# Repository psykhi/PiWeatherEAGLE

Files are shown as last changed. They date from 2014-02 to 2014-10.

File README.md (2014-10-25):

PiWeatherEAGLE
==============

This repository contains EAGLE boards/schematics/gerber files for the PiWeather weather station project.
To learn more, see http://theboredengineers.com.

main_indoor_sensor is an indoor board that can monitor temperature, humidity and pressure.
It is described here : http://theboredengineers.com/2014/05/piweather-part-4-first-pcbs/

rpi_shield is Raspberry Pi shield hosting a nRF24L01+ RF transimtter. 

If you are interested in this project, please visit http://theboredengineers.com, let a comment
or send an email to alex@theboredengineers.com

:)

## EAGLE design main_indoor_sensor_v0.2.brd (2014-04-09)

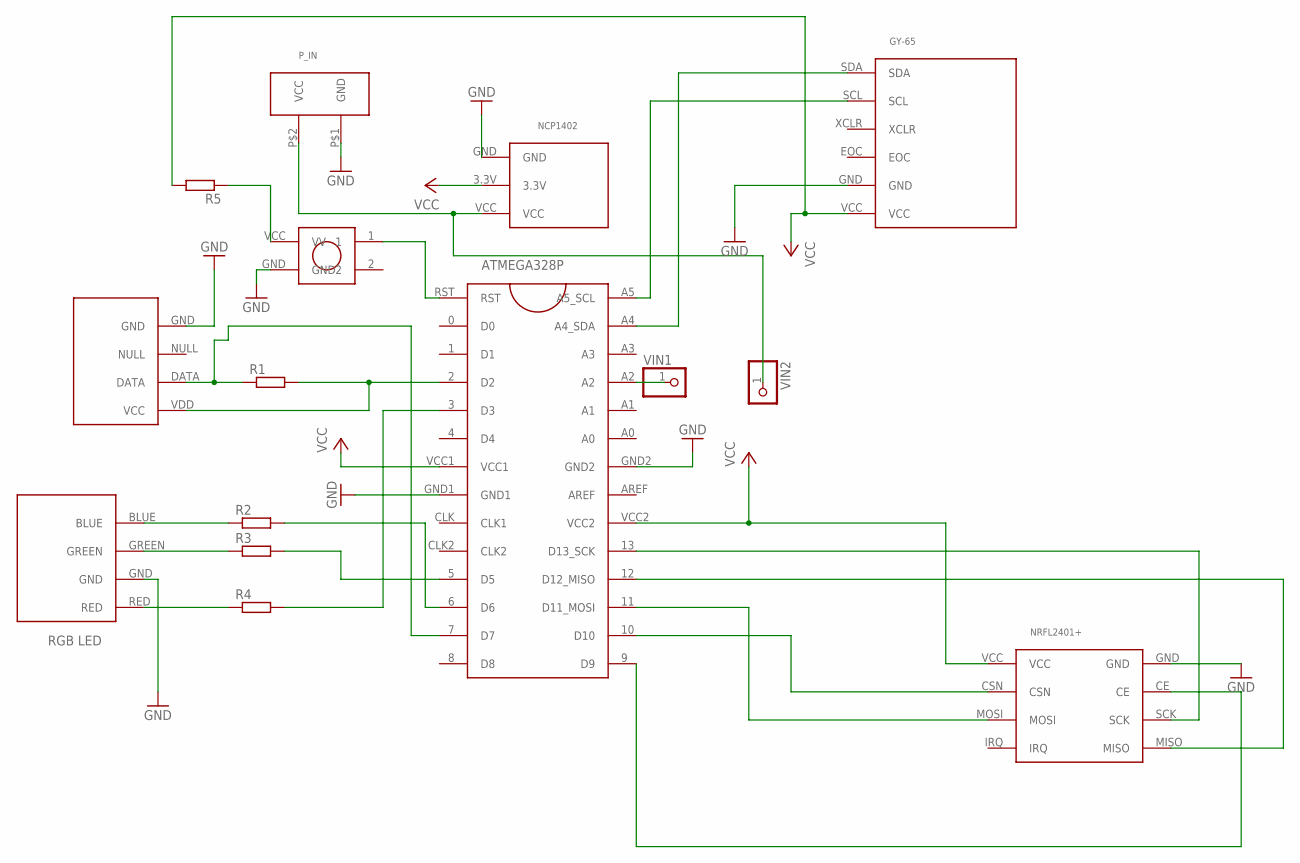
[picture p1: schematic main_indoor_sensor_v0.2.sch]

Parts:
GY-65: GY-65; GY_65
NCP1402: NCP1402SPARKFUN; NCP1402
NRFL2401+: NRFL24L01_8P; NRF24L01_10P
P_IN: 2PINCONNECTORSIMPLE; 2PINCONNECTOR
R1, R2, R3, R4, R5: R0204/7; 0204/7
U$1: ATMEGA328PARDUINO; ATMEGA328P
U$2: KRS_0612_OK; KRS0612_RIGHT
U$3: DHT22WHITE; DHT22
U$6: RGB_LED5MM; RGB_LED
VIN1, VIN2: PINHD-1X1; 1X01

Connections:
GND: GY-65.GND, NCP1402.GND, NRFL2401+.GND, P_IN.P$1 (GND), U$1.GND1, U$1.GND2, U$2.GND, U$3.GND, U$6.GND
unnamed: GY-65.SDA, U$1.A4 (A4_SDA)
unnamed: GY-65.SCL, U$1.A5 (A5_SCL)
unnamed: NRFL2401+.SCK, U$1.13 (D13_SCK)
unnamed: NRFL2401+.MISO, U$1.12 (D12_MISO)
unnamed: NRFL2401+.MOSI, U$1.11 (D11_MOSI)
unnamed: R1.2, U$1.2 (D2), U$3.VDD (VCC)
unnamed: R1.1, U$1.7 (D7), U$3.DATA
unnamed: R4.2, U$1.3 (D3)
unnamed: R2.1, U$6.BLUE
unnamed: R3.1, U$6.GREEN
unnamed: R2.2, U$1.6 (D6)
unnamed: R3.2, U$1.5 (D5)
unnamed: R4.1, U$6.RED
unnamed: NRFL2401+.CSN, U$1.10 (D10)
unnamed: NRFL2401+.CE, U$1.9 (D9)
unnamed: U$1.RST, U$2.1
unnamed: NCP1402.VCC, P_IN.P$2 (VCC), VIN2.1
unnamed: R5.1, U$2.VCC (VV)
unnamed: U$1.A2, VIN1.1
VCC: GY-65.VCC, NCP1402.3.3V, NRFL2401+.VCC, R5.2, U$1.VCC1, U$1.VCC2

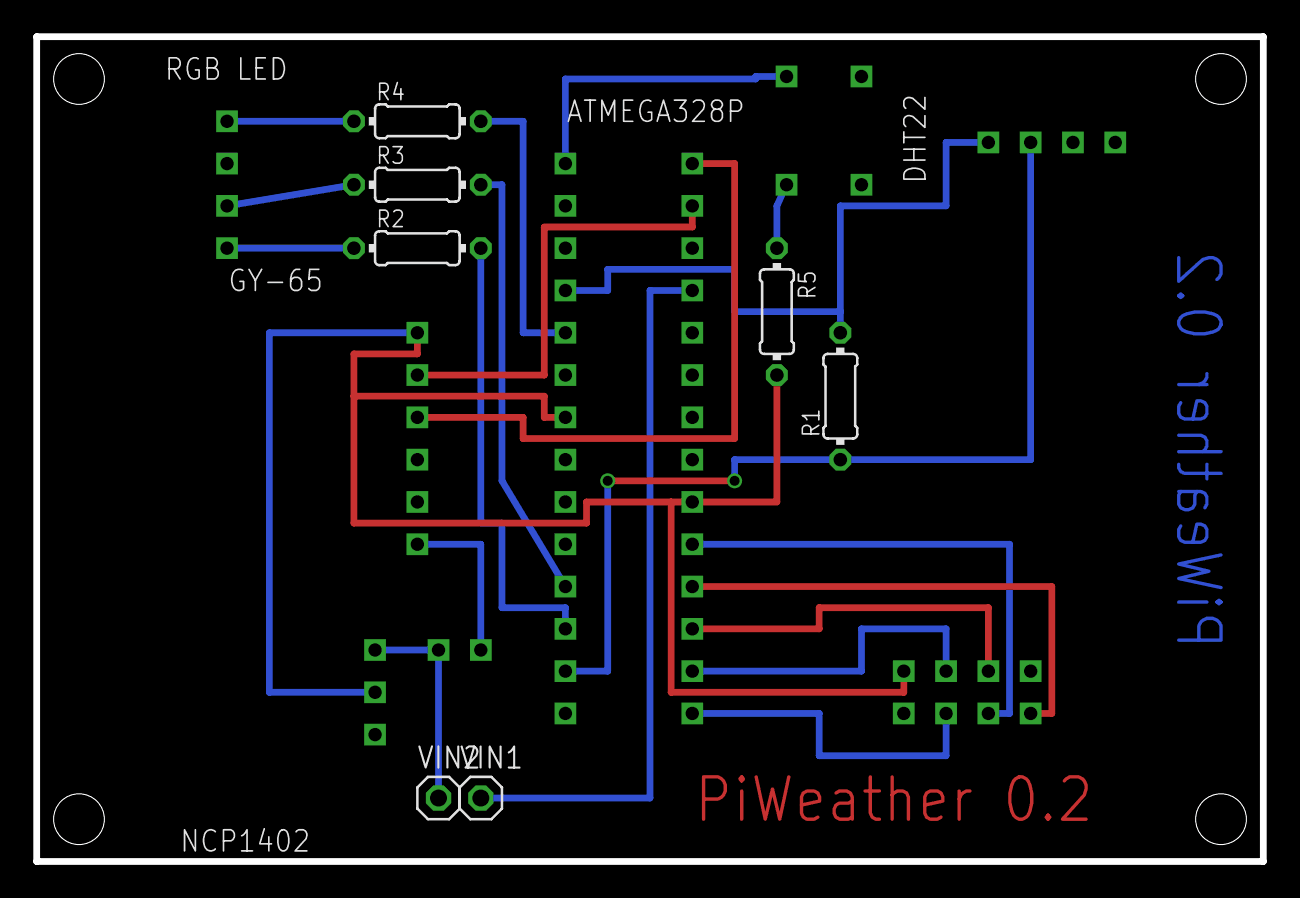
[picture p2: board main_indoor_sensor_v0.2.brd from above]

Board: 2 copper layers, 73.7 x 49.5 mm, 15 parts (0 on the bottom side), 21 nets.

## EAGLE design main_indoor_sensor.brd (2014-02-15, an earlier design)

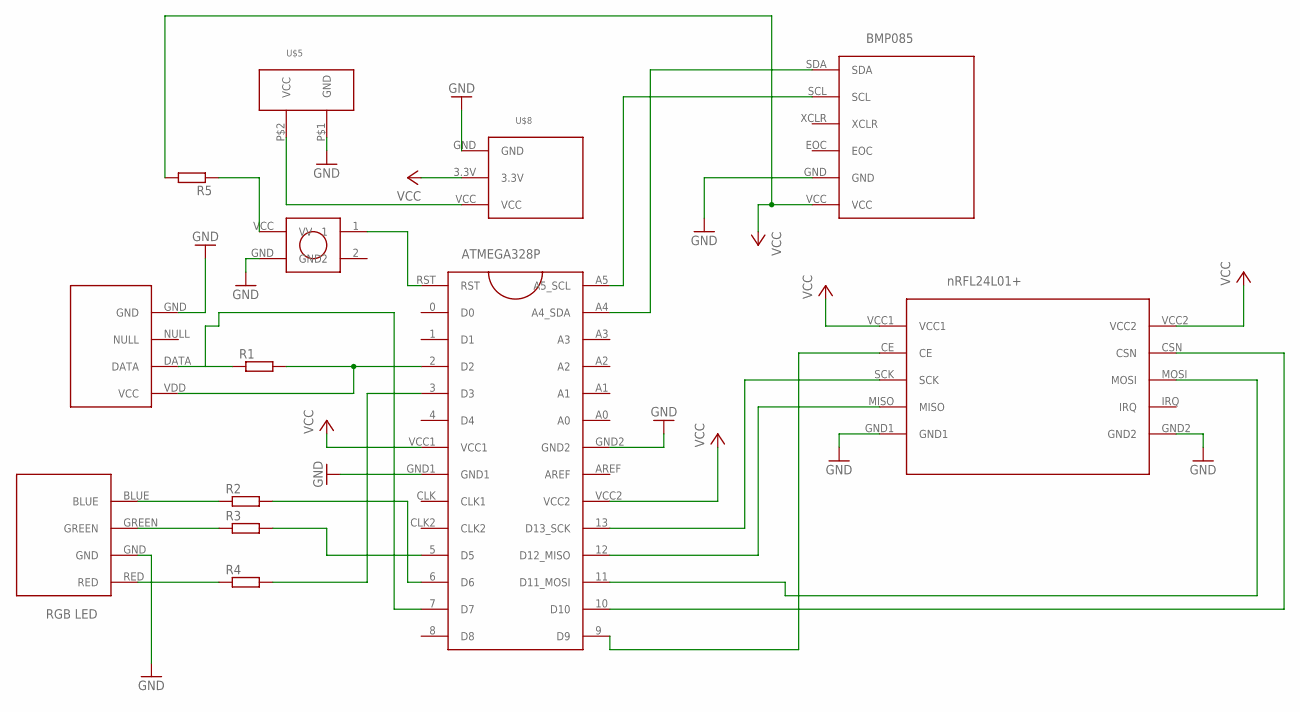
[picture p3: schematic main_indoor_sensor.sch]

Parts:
R1, R2, R3, R4, R5: R0204/7; 0204/7
U$1: ATMEGA328PARDUINO; ATMEGA328P
U$2: BMP085SPARKFUN; BMP085
U$3: DHT22WHITE; DHT22
U$4: NRF24L0110PINS; NRF24L01
U$5: 2PINCONNECTORSIMPLE; 2PINCONNECTOR
U$6: RGB_LED5MM; RGB_LED
U$7: KRS0612PUSH; KRS0612
U$8: NCP1402SPARKFUN; NCP1402

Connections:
GND: U$1.GND1, U$1.GND2, U$2.GND, U$3.GND, U$4.GND1, U$4.GND2, U$5.P$1 (GND), U$6.GND, U$7.GND, U$8.GND
unnamed: U$1.A4 (A4_SDA), U$2.SDA
unnamed: U$1.A5 (A5_SCL), U$2.SCL
unnamed: U$1.13 (D13_SCK), U$4.SCK
unnamed: U$1.12 (D12_MISO), U$4.MISO
unnamed: U$1.11 (D11_MOSI), U$4.MOSI
unnamed: R1.2, U$1.2 (D2), U$3.VDD (VCC)
unnamed: R1.1, U$1.7 (D7), U$3.DATA
unnamed: R4.2, U$1.3 (D3)
unnamed: R2.1, U$6.BLUE
unnamed: R3.1, U$6.GREEN
unnamed: R2.2, U$1.6 (D6)
unnamed: R3.2, U$1.5 (D5)
unnamed: R4.1, U$6.RED
unnamed: U$1.10 (D10), U$4.CSN
unnamed: U$1.9 (D9), U$4.CE
unnamed: U$1.RST, U$7.1
unnamed: U$5.P$2 (VCC), U$8.VCC
unnamed: R5.1, U$7.VCC (VV)
RASTNEST: R5.2, U$1.VCC1, U$1.VCC2, U$2.VCC, U$4.VCC1, U$4.VCC2, U$8.3.3V

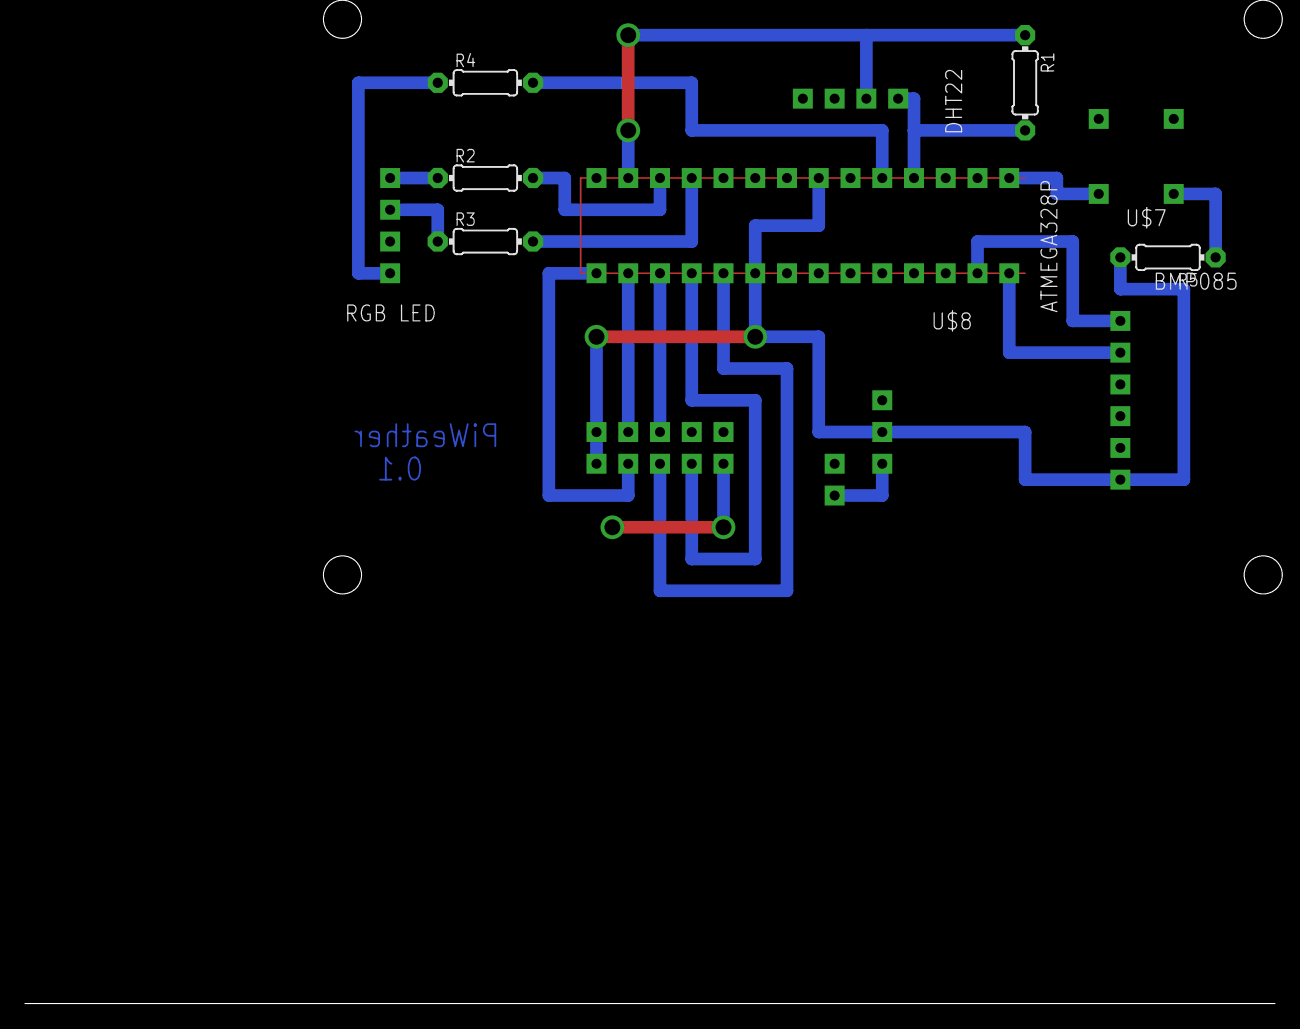
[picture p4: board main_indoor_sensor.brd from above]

Board: 2 copper layers, 13 parts (0 on the bottom side), 20 nets.

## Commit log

2014-02-14 fusion des deux repos eagle
    [main_indoor_sensor.brd, main_indoor_sensor.sch]
2014-02-15 Version 0.1 avec prototype créé
    [main_indoor_sensor.brd, main_indoor_sensor.sch]
2014-04-05 Added Seeedstudio design rules New version (0.2) of the board...ON VERRA
    [main_indoor_sensor_v0.2.brd, main_indoor_sensor_v0.2.sch]
2014-04-05 Added Gerber file...
    [main_indoor_sensor_v0.2.GBL, main_indoor_sensor_v0.2.GBO, main_indoor_sensor_v0.2.GBP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]
2014-04-09 Nouvelle version avec la board outline :o
    [main_indoor_sensor_v0.2.GBL, main_indoor_sensor_v0.2.GBO, main_indoor_sensor_v0.2.GBP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]
2014-09-10 Added Raspberry Pi GPIO header to the library
2014-09-10 Added RPI shield
    [rpi_shield.GBL, rpi_shield.GBO, rpi_shield.GBP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]
